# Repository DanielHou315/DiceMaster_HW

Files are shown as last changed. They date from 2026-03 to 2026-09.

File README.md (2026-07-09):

# DiceMaster HW

Hardware design files for the DiceMaster project, using KiCad.

## Board Status

The current production board is **PCB v1** (`PCB/DiceMaster_Router/`), finalized
for production on 2026-04-05 (commit `4ef69b5`, "finalized pcb v1 for prod").
Gerbers and the JLCPCB BOM under `PCB/DiceMaster_Router/gerbers/` are from this
run; the manufactured boards were received around mid-April 2026.

### Known issues (PCB v1 — unverified, to be handled later)

These issues were observed on the v1 boards but **not yet root-caused**:

1. **Some JST ports could not be soldered during manufacturing.** One or more of
   the JST GH SMD connectors (`J_A1`–`J_F1`, `J_BTN1`, `J_SWITCH1`, `J_FAN1`,
   `PiSugarPowerConnector1` — see `docs/runbooks/pcb-assembly.md` §4) could not
   be soldered on during assembly. Cause not yet determined (footprint/pad
   geometry vs. process).

2. **5V→3.3V converter does not work.** The onboard buck converter (IC1,
   TPS565201, SOT-23-6) did not produce a working 3.3 V rail after hand-soldering
   the part. It is **not yet known whether this is a design issue or a soldering
   issue** — this needs to be re-verified before the next production run. See the
   "No 3.3 V output" row in `docs/runbooks/pcb-assembly.md` §Troubleshooting and
   the converter subcircuit (IC1 / L1 / R_BOT1 / output caps) in the schematic.

> Status: both issues are **open and unverified**. Do not assume v1 boards have a
> working 3.3 V rail. Revisit during the next hardware bring-up / v2 design.

## KiCad MCP Server Setup

This project is configured with [kicad-mcp](https://github.com/lamaalrajih/kicad-mcp) to enable Claude Code to interact with KiCad projects directly.

### Prerequisites

- KiCad 9.0+ (installed at `/Applications/KiCad/KiCad.app`)
- Python 3.10+ and `uv`

### Installation

The MCP server is installed at `~/Applications/kicad-mcp`. To reinstall:

```bash
git clone https://github.com/lamaalrajih/kicad-mcp.git ~/Applications/kicad-mcp
cd ~/Applications/kicad-mcp
make install
cp .env.example .env
# Edit .env to set KICAD_SEARCH_PATHS to your project directory
```

### Usage

Start Claude Code from this directory — the `.mcp.json` file automatically connects the KiCad MCP server.

```bash
cd DiceMaster_HW
claude
```

Claude can then:

- **List projects** — discover KiCad projects in the configured search paths
- **Open projects** — launch KiCad with a specific project
- **Inspect schematics** — read components, nets, and symbols
- **Analyze PCBs** — view board properties, footprints, and design rules
- **Manage libraries** — search and retrieve KiCad symbols/footprints

### Configuration

- **`.mcp.json`** — MCP server config (points to the kicad-mcp installation)
- **`~/Applications/kicad-mcp/.env`** — KiCad paths and project search directories

To add more search paths, edit `~/Applications/kicad-mcp/.env`:

```
KICAD_SEARCH_PATHS=~/Code/DiceMaster/DiceMaster_HW,~/other/projects
```

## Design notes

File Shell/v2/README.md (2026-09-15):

# DiceMaster Shell v2

## BOM

**3D Prints**

- 1x Base Frame
- 1x Base Inserts/USB SW Plate
- 1x Base Inserts/Button Plate (for future use)
- 1x Screen Backplate With Fan
- 5x Screen Backplate

Print in PLA at 20% infill. 

**Components**

- 1x [Raspberry Pi CM4 with 16GB+ eMMC storage](https://www.newark.com/raspberry-pi/cm4102016/rpi-module-4-2gb-ram-16gb-emmc/dp/86AH2097)
- 1x [WaveShare CM4 Nano Base Board (B)](https://www.waveshare.com/cm4-nano-b.htm)
- 6x [AdaFruit 4' 480x480 NoTouch Screen](https://www.adafruit.com/product/5827)
- 6x [AdaFruit Qualia ESP32-S3 for TTL RGB-666 Displays](https://www.adafruit.com/product/5800)
- 1x custom PCB board
- 1x [30mm blower fan](https://www.amazon.com/WINSINN-Blower-Hydraulic-Bearing-Turbine/dp/B08MKRL4GS)
- 1x 10cm USB-C to USB-C cable
- 1x 15cm USB-C to USB-C cable
- 1x [USB-A to USB-C adapter](https://www.amazon.com/Female-Male-Adapter-3Pack-Gray/dp/B07Z66MK6L)
- Abundant JST-GH connectors
- Abundant M2.5 x 6mm screws
- Abundant M2.5 * 8mm screws
- Abundant Wires
- Abundant 1/8 inch clear Acrylic

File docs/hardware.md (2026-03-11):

# Programmable Dice Hardware

We used
- [Adafruit LCD 4’ square display ](https://www.adafruit.com/product/5827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)
- [Esp32-s3 controller](https://www.adafruit.com/product/5800) for the above display. [Guides for using the board](https://learn.adafruit.com/adafruit-qualia-esp32-s3-for-rgb666-displays). 
- We name a Screen Module an assembly of the above screen and an ESP 32 processor along with its external shell. 

## Dimensions (for physical design)

ESP32 Board
- Board dimensions: 44.35 x 51.7mm. 
- Between holes: 31.15 x 36.85
- Hole dimension: 2.5mm (~0.1 inch).

Screen: 
- Board dimensions: 75.00mm x 79.10mm

Raspberry Pi 3B+ board: 
- Between holes: 49 x 58 mm
- Hole dimension: 2.5mm

PiSugar 3S Battery
- Holes same as above, height 19mm

Raspberry Pi Compute Module 4 
- Board dimensions: 40 x 55mm
- Between holes 33 x 48 mm
- Hole dimension: 2.5 mm

## Pinout Design

- [Raspberry Pi pinout](https://pinout.xyz/)
- [ESP-32 S3 guide](https://learn.adafruit.com/adafruit-qualia-esp32-s3-for-rgb666-displays)
- [Connecting screen to Raspberry Pi](https://pinout.xyz/pinout/spi)
- [Connecting MPU6050](https://www.instructables.com/How-to-Use-the-MPU6050-With-the-Raspberry-Pi-4/)

## Electrical Design

### Data Lines
**Screens**
We use 3 SPI buses to connect a total of six screens. To minimize CS switching time, we design an application layer protocol that is similar to CAN, where devices choose to accept/respond to messages based on the device ID. 

SPI 0: 
- SCK: 23
- MISO: 21 (not used)
- MOSI: 19
- CS: 24 (for both screens)

SPI 1: 
- SCK: 40
- MISO: 35 (not used)
- MOSI: 38
- CS: 12 (for both screens)

SPI 3: 
- SCK: 5
- MISO: 28 (not used)
- MOSI: 3
- CS: 27 (for both screens)

**IMU/Battery**
IMU and Battery uses I2C6. 
- SDA: 15
- SCL: 16

**Power Switch**

**Status LED**

**Buttons**

### Power Lines

### PCB

Yuzhen is working on this

## HW v2

### Reliability

### Cost Reduction

**Whiteboard version**: 

[Example dice](https://www.amazon.com/Scribbledo-Multipurpose-Colorful-Educational-Classroom/dp/B0B3S75YCV). 

### Batter Life Improvement

For HW v1, the batter lasts about 45 minutes when all displays are active, as was tested during serious play.

### Additional features

1. Cooling: adding a fan for Raspberry Pi, air channels, and optimized layout of 5V to 3.3V regulators. 
2.

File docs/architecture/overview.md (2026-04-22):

# Hardware Architecture Overview

## Summary

DiceMaster is a programmable electronic die with six faces. Each face displays a screen driven by a dedicated ESP32-S3 processor. A central Raspberry Pi (CM4 or 3B+) coordinates all six faces over SPI and reads orientation from an IMU over I2C. A TPS565201 buck converter on the Router PCB steps the battery voltage down to 3.3 V for all logic.

---

## Boards and Modules

### Raspberry Pi (Central Controller)

The Raspberry Pi acts as the main application processor. Either a Raspberry Pi 3B+ or a Compute Module 4 (CM4) is supported:

- **Raspberry Pi 3B+**: 85 × 56 mm, mounting holes 49 × 58 mm apart, 2.5 mm diameter.
- **Raspberry Pi CM4**: 40 × 55 mm, mounting holes 33 × 48 mm apart, 2.5 mm diameter.

The Pi runs the `dicemaster_central` ROS 2 package and owns the SPI and I2C buses.

### DiceMaster Router PCB (`PCB/DiceMaster_Router/`)

The Router is a custom 2-layer KiCad PCB (≤ 60 × 60 mm, 1 oz copper) that acts as the electrical hub of the dice. It provides:

- A **2×20 pin female header (J1)** that mates directly to the Raspberry Pi 40-pin GPIO header.
- **Six JST GH 6-pin connectors (J_A1–J_F1)**, one per screen/ESP32 face module, carrying SPI data lines and 3.3 V power.
- A **TPS565201DDCR** synchronous buck regulator (5 V → 3.3 V, SOT-23-6) with supporting passives (L1, C1/C3/C_OUT1-3, R_Top1/R_BOT1, C_BST1).
- A **2N7002 N-channel MOSFET (Q_FAN1)** and **1N5819 Schottky diode (D_FAN1)** for PWM-controlled fan driving.
- A **GY-BMI160 IMU breakout** socket (U1, 7+5 pin headers, 10.16 mm row spacing) for orientation sensing over I2C.
- A **JST GH 5-pin connector (J_BTN1)** for the button array.
- A **JST GH 3-pin connector (J_SWITCH1)** for the power switch.
- A **JST GH 2-pin connector (J_FAN1)** for the 30 mm 5 V blower fan.
- A **JST GH 2-pin connector (PiSugarPowerConnector1)** for the PiSugar 3S battery board.

Custom KiCad symbols and footprints for the TPS565201 and BMI160 breakout live in `PCB/DiceMaster_Router/Components/` and `Components.pretty/`.

### Screen Modules (× 6)

Each screen module is an assembly of:

- **Adafruit 4-inch square RGB666 LCD** (Adafruit #5827), PCB 75.00 × 79.10 mm.
- **Adafruit Qualia ESP32-S3 controller** (Adafruit #5800), PCB 44.35 × 51.7 mm, mounting holes 31.15 × 36.85 mm apart, 2.5 mm diameter.
- A physical shell that forms one face of the die enclosure (see Enclosure below).

Each ESP32-S3 receives commands from the Pi over SPI and drives its attached display directly.

### PiSugar 3S Battery Board

The PiSugar 3S attaches to the underside of the Raspberry Pi. Its mounting holes match the Pi's 49 × 58 mm pattern. It connects to the Router PCB via `PiSugarPowerConnector1`. Battery life is approximately 45 minutes with all six displays active.

---

## Interconnects

### SPI (Pi → ESP32-S3 face modules)

Three SPI buses each carry two face modules. All six modules share a CAN-inspired application-layer protocol: each ESP32-S3 accepts or ignores messages based on a device ID, so a single CS line per bus services two modules without per-device chip-select toggling.

| Bus | SCK | MOSI | MISO (unused) | CS |
|---|-----|---|---|----|
| SPI 0 | 23  | 19 | 21 | 24 |
| SPI 1 | 40  | 38 | 35 | 12 |
| SPI 3 | 5 | 3 | 28 | 27 |

Pin numbers are Raspberry Pi physical/BCM GPIO as documented at [pinout.xyz](https://pinout.xyz/pinout/spi).

Each face module connects to the Router PCB via a JST GH 6-pin cable (J_A1–J_F1), carrying SCK, MOSI, CS, 3.3 V, and GND.

### I2C (Pi → IMU and Battery)

The BMI160 IMU breakout and PiSugar battery management share **I2C bus 6**:

- SDA: GPIO 15
- SCL: GPIO 16

### Power Distribution

```
Battery (LiPo via PiSugar 3S)
  └─► PiSugar board → Raspberry Pi (5 V USB-style)
  └─► Router PCB PiSugarPowerConnector1
        └─► TPS565201 buck converter (5 V → 3.3 V)
              └─► 3.3 V rail → six face module JST connectors
              └─► 3.3 V rail → logic on Router PCB
  └─► Fan connector (5 V, MOSFET-switched via Q_FAN1)
```

---

## Enclosure (shell/)

The `shell/` directory holds the physical enclosure design files for the dice body. The shell is shaped as a cube with six flat faces; each face seats one screen module assembly. The enclosure design is currently a placeholder — no CAD files have been added yet.

Reference for physical form factor: [Scribbledo foam cube dice](https://www.amazon.com/Scribbledo-Multipurpose-Colorful-Educational-Classroom/dp/B0B3S75YCV).

---

## HW v1 vs v2

**v1** used Adafruit dev boards with external wiring. Battery life was ~45 minutes under full load.

**v2 goals** (in progress): custom compact PCB (this Router board), improved battery life, cooling fan, optimized 5 V→3.3 V regulator layout, and reduced cost via bare modules.

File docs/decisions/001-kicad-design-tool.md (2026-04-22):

# ADR-001: KiCad as PCB Design Tool

## Status

Accepted

## Context

DiceMaster requires custom PCB design for the Router board. The design files must be:

- Stored in Git alongside the rest of the project source.
- Reproducible on any developer machine without a paid license or cloud dependency.
- Compatible with standard PCB fabrication services (JLCPCB, PCBWay) that accept Gerber outputs.

The team is a small hardware/software group on macOS and Linux. Tooling cost and vendor lock-in are primary concerns.

## Decision

Use **KiCad 9.0+** as the sole PCB design tool.

- The project file is `PCB/DiceMaster_Router/DiceMaster_Router.kicad_pro`.
- Schematics use `.kicad_sch` format; board layout uses `.kicad_pcb`.
- Custom symbols and footprints specific to this project (TPS565201, BMI160 breakout) live in `PCB/DiceMaster_Router/Components/` and `Components.pretty/` and are checked into Git.
- Gerber outputs are committed to `PCB/DiceMaster_Router/gerbers/` for traceability.
- The project is configured with a [kicad-mcp](https://github.com/lamaalrajih/kicad-mcp) server so Claude Code can inspect schematics and PCB files directly.

## Consequences

**Positive:**

- KiCad is free and open-source (GPL). No license cost.
- All file formats (`.kicad_sch`, `.kicad_pcb`, `.kicad_pro`) are plain text (S-expression). Git diffs are human-readable and merge conflicts are resolvable.
- Ships with a large built-in symbol and footprint library covering most standard passive and active components.
- Cross-platform: runs on macOS, Linux, and Windows.
- Gerber export is well-supported and accepted by all major PCB fabs.

**Negative:**

- Steeper initial learning curve than Eagle's legacy UI or EasyEDA's guided workflow.
- KiCad's scripting API (Python) is powerful but sparsely documented compared to commercial tools.
- Version upgrades (e.g., KiCad 8 → 9) occasionally change file formats, requiring migration.

## Alternatives Considered

**Eagle (Autodesk)**
Eagle was the de-facto hobbyist standard before Autodesk acquisition. It is now bundled with Fusion 360 under a subscription model. File format is proprietary XML; while text-based, diffs are noisy and imports into other tools are lossy. Rejected due to cost and vendor lock-in.

**EasyEDA (LCSC/JLCPCB)**
Browser-based tool tightly integrated with JLCPCB's component catalog. Convenient for ordering, but files live in the cloud, offline access is limited, and version control requires manual JSON export. Rejected because reproducibility and Git integration are first-class requirements for this project.

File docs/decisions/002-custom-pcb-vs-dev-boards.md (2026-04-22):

# ADR-002: Custom PCB vs Off-the-Shelf Dev Boards

## Status

Accepted

## Context

DiceMaster needs to fit a Raspberry Pi, six ESP32-S3 screen controllers, an IMU, a battery board, a buck regulator, and a cooling fan inside a cube-shaped enclosure. The enclosure face dimensions are constrained by the 75 × 79 mm screen panels.

**Prototype v1** used off-the-shelf Adafruit dev boards (Adafruit Qualia ESP32-S3 #5800, 44.35 × 51.7 mm each) wired together with jumper cables. This proved the software stack but exposed hardware problems:

- The Qualia ESP32-S3 dev boards protrude connectors (USB-C, JST, headers) on all four edges, making flush face mounting impossible.
- Six individual dev boards plus a breadboard-style wiring harness do not fit reliably inside the enclosure.
- Loose jumper wire connections caused intermittent SPI failures during handling.
- Battery life was ~45 minutes under full load, partly due to inefficient power distribution.

A production-grade design requires tight, mechanically stable integration.

## Decision

Use a **custom DiceMaster Router PCB** (in `PCB/DiceMaster_Router/`) that centralises all inter-board routing.

Key design choices on the custom PCB:

- **Bare ESP32-S3 modules** (via Adafruit Qualia boards retained for now, connected via JST GH 6-pin cables rather than loose jumpers) replace the prototype wiring harness.
- **JST GH 6-pin connectors (J_A1–J_F1)** provide one keyed, latching connector per face — no loose wires.
- **TPS565201 buck converter** on the Router board provides a regulated 3.3 V rail directly, eliminating per-board linear regulators.
- The Router board footprint is ≤ 60 × 60 mm so it fits beneath the Pi inside the enclosure.
- Gerbers are committed and have been ordered from JLCPCB with SMD assembly for passive components.

## Consequences

**Positive:**

- Compact, mechanically reliable form factor — all inter-board connections are short, keyed cables.
- Centralised power regulation reduces heat and improves efficiency over per-board LDOs.
- Production-ready: the PCB can be re-ordered from JLCPCB using the committed Gerber and BOM files.
- Eliminates the intermittent SPI failures seen with jumper wiring.

**Negative:**

- PCB manufacturing lead time (~5–7 business days for JLCPCB standard service) slows hardware iteration.
- SMD soldering or PCBA service required for passive components; hand-soldering the TPS565201 SOT-23-6 demands fine-pitch skill.
- A PCB spin is needed to change any electrical interface.

## Alternatives Considered

**Prototype v1: dev boards with breakout wiring**
Used in the initial prototype. Fast to iterate, but mechanically unreliable and physically too large for the target enclosure. Retained as a software development reference only.

**Flexible PCB (FPC)**
An FPC could route connections along the inside faces of the cube enclosure. Rejected for v2 because FPC tooling and design complexity is significantly higher, and the rigid Router PCB approach already solves the mechanical reliability problem at lower cost.

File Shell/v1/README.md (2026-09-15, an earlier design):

# DiceMaster Shell v1

The v1 shell (concluded Aug 8, 2025), is a fast prototype design with exoskeleton-like design. It is designed to be easier for fast iteration and

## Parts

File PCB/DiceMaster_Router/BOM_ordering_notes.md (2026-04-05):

# DiceMaster Router - BOM & Ordering Notes

## JLCPCB SMD Assembly Parts

### Resistors (0402, 1%)
| Ref | Value | Package | Notes |
|-----|---|---|---|
| R_FG1 | 1kΩ | 0402 | MOSFET gate resistor |
| R_FPD1 | 100kΩ | 0402 | MOSFET gate pull-down |
| R_Top1 | 100kΩ | 0402 | TPS565201 feedback divider top |
| R_BOT1 | 30.1kΩ | 0402 | TPS565201 feedback divider bottom. **Must be 1% tolerance** — sets 3.3V output voltage |

### Capacitors (0402 / 0805)
| Ref | Value | Package | Notes |
|-----|---|---|---|
| C_BST1 | 100nF | 0402 | TPS565201 bootstrap cap |
| C1 | 22µF | 0805 | TPS565201 input cap. **Must be ≥10V rated.** e.g., Samsung CL21A226MAQNNNE |
| C3 | 22µF | 0805 | TPS565201 input cap. Same spec as C1 |
| C_OUT1 | 22µF | 0805 | TPS565201 output cap. ≥10V rated |
| C_OUT2 | 22µF | 0805 | TPS565201 output cap. ≥10V rated |
| C_OUT3 | 22µF | 0805 | TPS565201 output cap. ≥10V rated |

**WARNING:** 0805 22µF ceramic caps at 6.3V rating have severe DC bias derating — at 5V they may only provide ~10µF effective capacitance. Always pick **≥10V rated** parts to maintain full capacitance at operating voltage.

### Inductor
| Ref | Value | Package | Notes |
|-----|---|---|---|
| L1 | 3.3µH | 5x5mm (NR-50xx) | Power inductor for TPS565201. **Must be rated ≥3A saturation current.** Search JLCPCB for "3.3uH 5040" or "3.3uH 5020". e.g., Sunlord SWPA5040S3R3NT |

### Semiconductor
| Ref | Value | Package | Notes |
|-----|---|---|---|
| IC1 | TPS565201DDCR | SOT-23-6 (SOT95P280X110-6N) | 5V→3.3V buck converter |
| Q_FAN1 | 2N7002 | SOT-23 | N-channel MOSFET, fan driver. 115mA max continuous |
| D_FAN1 | 1N5819 | SOD-323 | Schottky flyback diode. SOD-323 equivalent: 1N5819HW or B5819W |

### Fan Current Budget
- Fan: WINSINN 30mm 5V Blower (0.09A / 0.5W)
- Q_FAN (2N7002) rated 115mA continuous
- Margin: 26mA (23%) — acceptable for this fan, but do NOT substitute a larger fan without upgrading the MOSFET (e.g., IRLML6344 for >1A fans)

## Hand-Soldered Connectors

| Ref | Part | Notes |
|-----|---|---|
| J1 | 2x20 pin socket header, 2.54mm | Raspberry Pi 40-pin female header |
| J_A1–J_F1 | SM06B-GHS-TB | JST GH 6-pin SMD horizontal |
| J_BTN1 | SM05B-GHS-TB | JST GH 5-pin SMD horizontal |
| J_SWITCH1 | SM03B-GHS-TB | JST GH 3-pin SMD horizontal |
| J_FAN1 | SM02B-GHS-TB | JST GH 2-pin SMD horizontal |
| PiSugarPowerConnector1 | SM02B-GHS-TB | JST GH 2-pin SMD horizontal |

## IMU Breakout (separate board, plugs in)

| Part | Notes |
|---|---|
| GY-BMI160 | 18.3mm × 13.3mm breakout board. Mounts via pin headers into U1 footprint (7+5 pin, 10.16mm row spacing, 2.54mm pitch) |

## PCB Specs for JLCPCB Order
- Max board size: 60mm × 60mm
- Layers: 2 (or 4 if routing is tight)
- Copper weight: 1oz standard
- Surface finish: HASL or LeadFree HASL

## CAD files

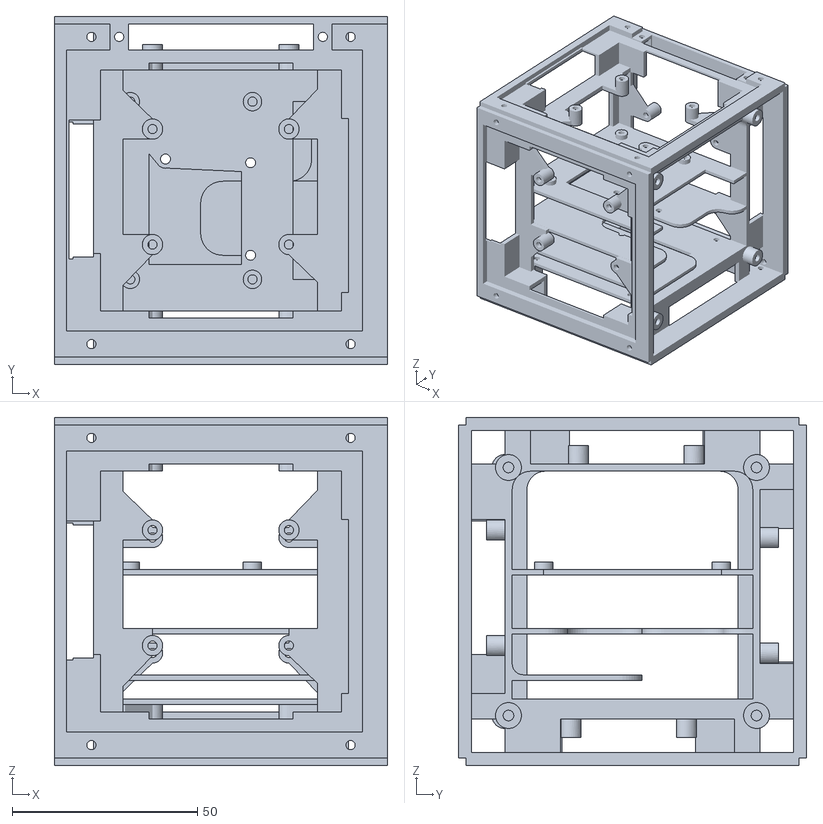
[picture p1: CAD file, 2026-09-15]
Shell/v2/Base Frame/Base Frame.stl
90.0 x 94.0 x 94.0

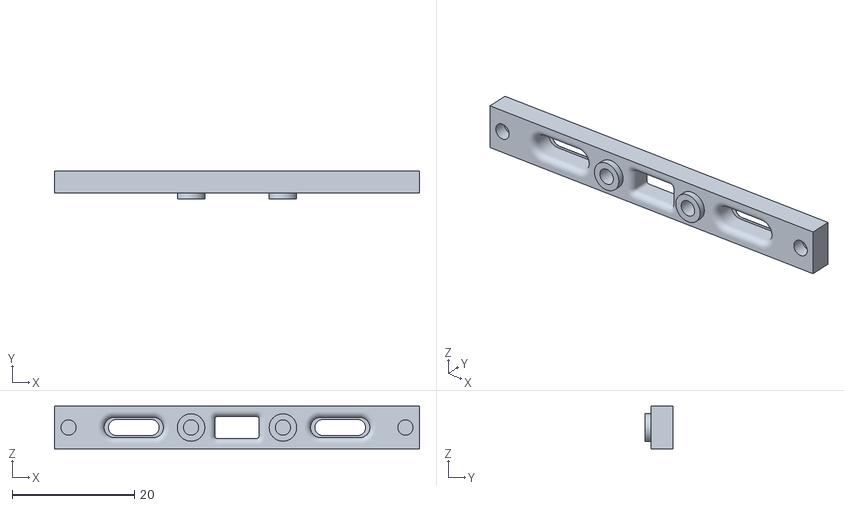
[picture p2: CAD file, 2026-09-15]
Shell/v2/Base Inserts/USB SW Plate.stl
59.6 x 4.53 x 7.00

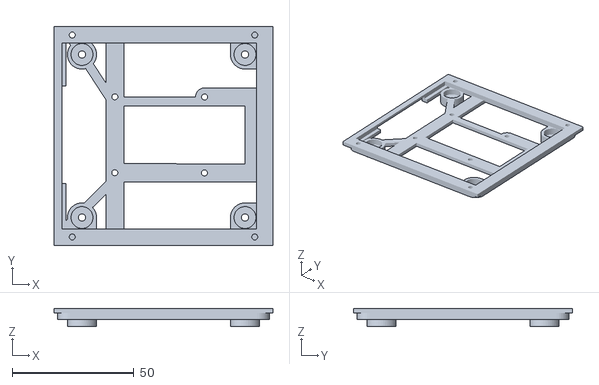
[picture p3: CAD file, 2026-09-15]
Shell/v2/Screen Backplate/Screen BackPlate.stl
90.0 x 90.0 x 7.50

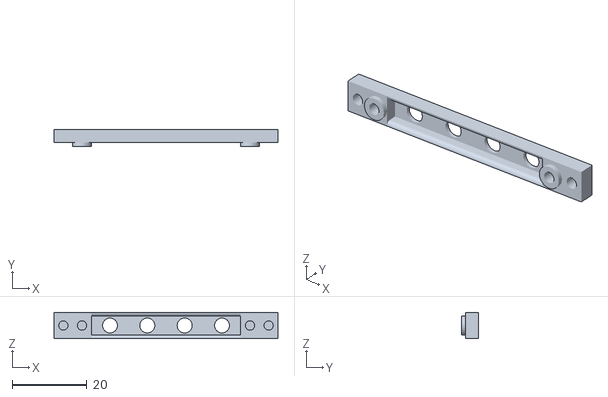
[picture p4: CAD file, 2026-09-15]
Shell/v2/Base Inserts/Button Plate.stl
60.0 x 4.53 x 7.00

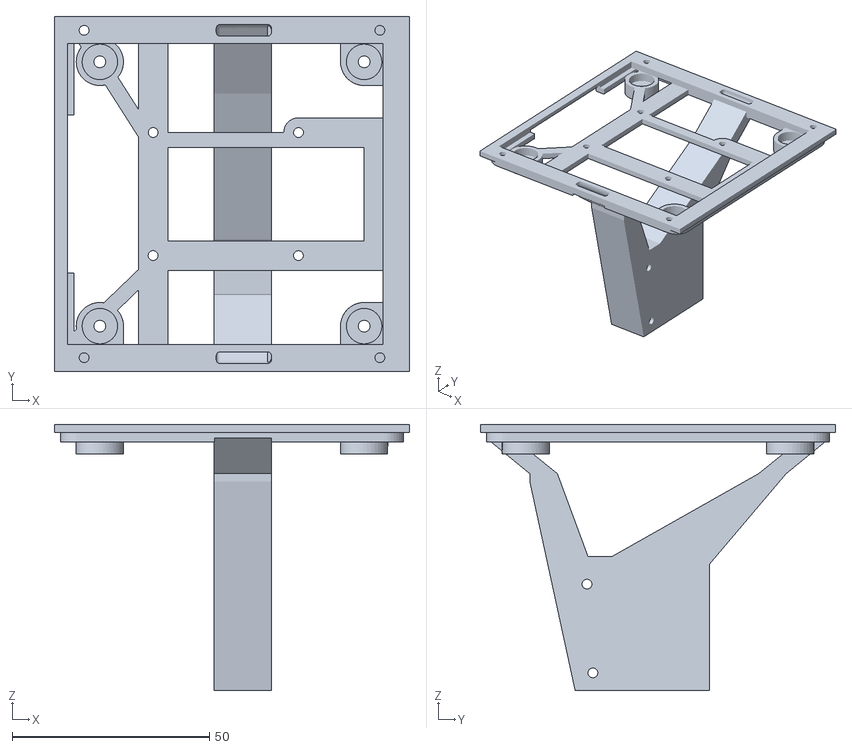
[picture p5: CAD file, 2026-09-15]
Shell/v2/Screen Backplate/Screen Backplate With Fan.stl
90.0 x 90.0 x 67.5

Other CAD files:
Shell/v2/Base Frame/Base Frame.f3d
Shell/v2/Base Inserts/Button Plate.f3d
Shell/v2/Base Inserts/USB SW Plate.f3d
Shell/v2/Screen Backplate/Screen Backplate With Fan.f3d
Shell/v2/Screen Backplate/Screen Backplate.f3d

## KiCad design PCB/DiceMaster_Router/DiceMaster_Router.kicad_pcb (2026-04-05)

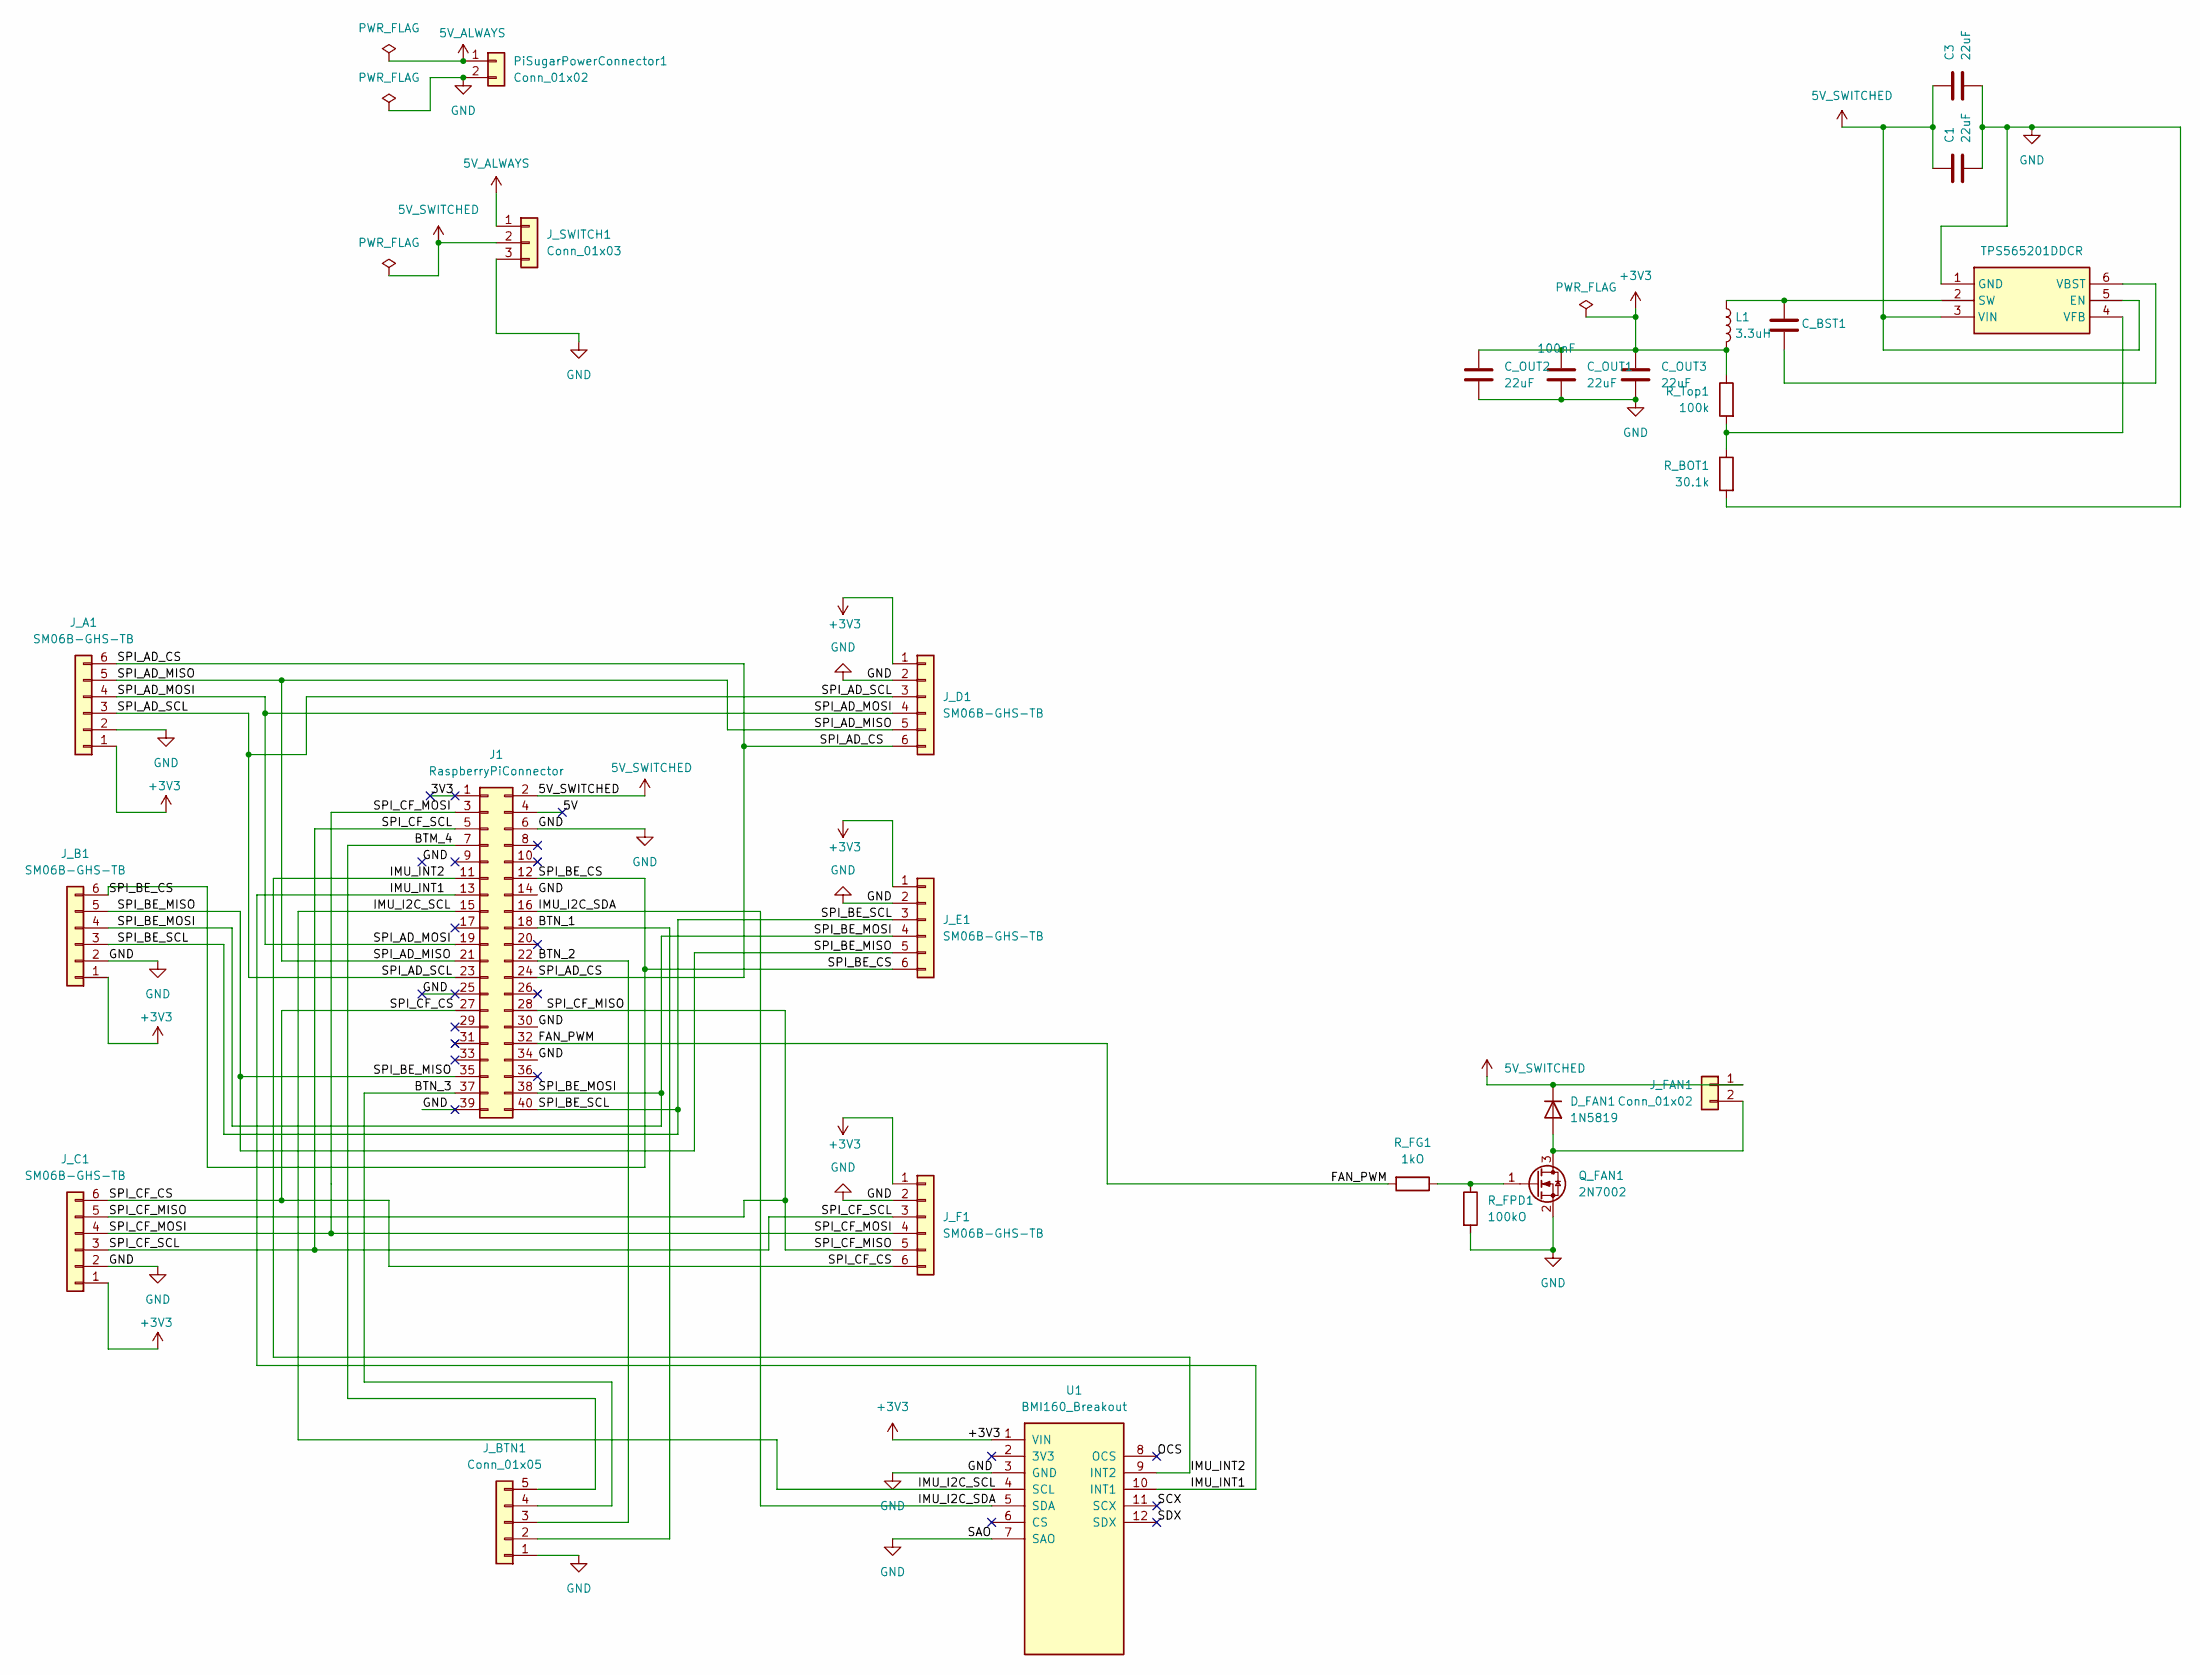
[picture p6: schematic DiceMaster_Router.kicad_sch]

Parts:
C1, C3: 22uF; C_0805_2012Metric
C_BST1: 100nF; C_0402_1005Metric
C_OUT1, C_OUT2, C_OUT3: 22uF; C_0805_2012Metric
D_FAN1: 1N5819; D_SOD-323
IC1: TPS565201DDCR; SOT95P280X110-6N; Manufacturer_Part_Number TPS565201DDCR; Mouser Part Number 595-TPS565201DDCR
J1: RaspberryPiConnector; PinSocket_2x20_P2.54mm_Vertical
J_A1: SM06B-GHS-TB; JST_GH_SM06B-GHS-TB_1x06-1MP_P1.25mm_Horizontal
J_B1: SM06B-GHS-TB; JST_GH_SM06B-GHS-TB_1x06-1MP_P1.25mm_Horizontal
J_BTN1: Conn_01x05; JST_GH_SM05B-GHS-TB_1x05-1MP_P1.25mm_Horizontal
J_C1: SM06B-GHS-TB; JST_GH_SM06B-GHS-TB_1x06-1MP_P1.25mm_Horizontal
J_D1: SM06B-GHS-TB; JST_GH_SM06B-GHS-TB_1x06-1MP_P1.25mm_Horizontal
J_E1: SM06B-GHS-TB; JST_GH_SM06B-GHS-TB_1x06-1MP_P1.25mm_Horizontal
J_F1: SM06B-GHS-TB; JST_GH_SM06B-GHS-TB_1x06-1MP_P1.25mm_Horizontal
J_FAN1: Conn_01x02; JST_GH_SM02B-GHS-TB_1x02-1MP_P1.25mm_Horizontal
J_SWITCH1: Conn_01x03; JST_GH_SM03B-GHS-TB_1x03-1MP_P1.25mm_Horizontal
L1: 3.3uH; L_Taiyo-Yuden_NR-50xx
PiSugarPowerConnector1: Conn_01x02; JST_GH_SM02B-GHS-TB_1x02-1MP_P1.25mm_Horizontal
Q_FAN1: 2N7002; SOT-23
R_BOT1: 30.1k; R_0402_1005Metric
R_FG1: 1kO; R_0402_1005Metric
R_FPD1: 100kO; R_0402_1005Metric
R_Top1: 100k; R_0402_1005Metric
U1: BMI160_Breakout

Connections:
5V_ALWAYS: J_SWITCH1.1, PiSugarPowerConnector1.1
5V_SWITCHED: C1.1, C3.1, D_FAN1.1 (K), IC1.3 (VIN), IC1.5 (EN), J1.2, J_FAN1.1, J_SWITCH1.2
+3V3: C_OUT1.1, C_OUT2.1, C_OUT3.1, J_A1.1, J_B1.1, J_C1.1, J_D1.1, J_E1.1, J_F1.1, L1.2, R_Top1.1, U1.1 (VIN)
/3V3: J1.1
/5V: J1.4
/BTM_4: J1.7, J_BTN1.5
/BTN_1: J1.18, J_BTN1.2
/BTN_2: J1.22, J_BTN1.3
/BTN_3: J1.37, J_BTN1.4
/FAN_PWM: J1.32, R_FG1.2
/IMU_I2C_SCL: J1.15, U1.4 (SCL)
/IMU_I2C_SDA: J1.16, U1.5 (SDA)
/IMU_INT1: J1.13, U1.10 (INT1)
/IMU_INT2: J1.11, U1.9 (INT2)
/OCS: U1.8 (OCS)
/SCX: U1.11 (SCX)
/SDX: U1.12 (SDX)
/SPI_AD_CS: J1.24, J_A1.6, J_D1.6
/SPI_AD_MISO: J1.21, J_A1.5, J_D1.5
/SPI_AD_MOSI: J1.19, J_A1.4, J_D1.4
/SPI_AD_SCL: J1.23, J_A1.3, J_D1.3
/SPI_BE_CS: J1.12, J_B1.6, J_E1.6
/SPI_BE_MISO: J1.35, J_B1.5, J_E1.5
/SPI_BE_MOSI: J1.38, J_B1.4, J_E1.4
/SPI_BE_SCL: J1.40, J_B1.3, J_E1.3
/SPI_CF_CS: J1.27, J_C1.6, J_F1.6
/SPI_CF_MISO: J1.28, J_C1.5, J_F1.5
/SPI_CF_MOSI: J1.3, J_C1.4, J_F1.4
/SPI_CF_SCL: J1.5, J_C1.3, J_F1.3
GND: C1.2, C3.2, C_OUT1.2, C_OUT2.2, C_OUT3.2, IC1.1 (GND), J1.6, J1.14, J1.25, J1.30, J1.34, J1.39, J_A1.2, J_B1.2, J_BTN1.1, J_C1.2, J_D1.2, J_E1.2, J_F1.2, J_SWITCH1.3, PiSugarPowerConnector1.2, Q_FAN1.2 (S), R_BOT1.2, R_FPD1.2, U1.3 (GND), U1.7 (SAO)
unnamed: D_FAN1.2 (A), J_FAN1.2, Q_FAN1.3 (D)
unnamed: C_BST1.1, IC1.2 (SW), L1.1
unnamed: C_BST1.2, IC1.6 (VBST)
unnamed: IC1.4 (VFB), R_BOT1.1, R_Top1.2
unnamed: Q_FAN1.1 (G), R_FG1.1, R_FPD1.1

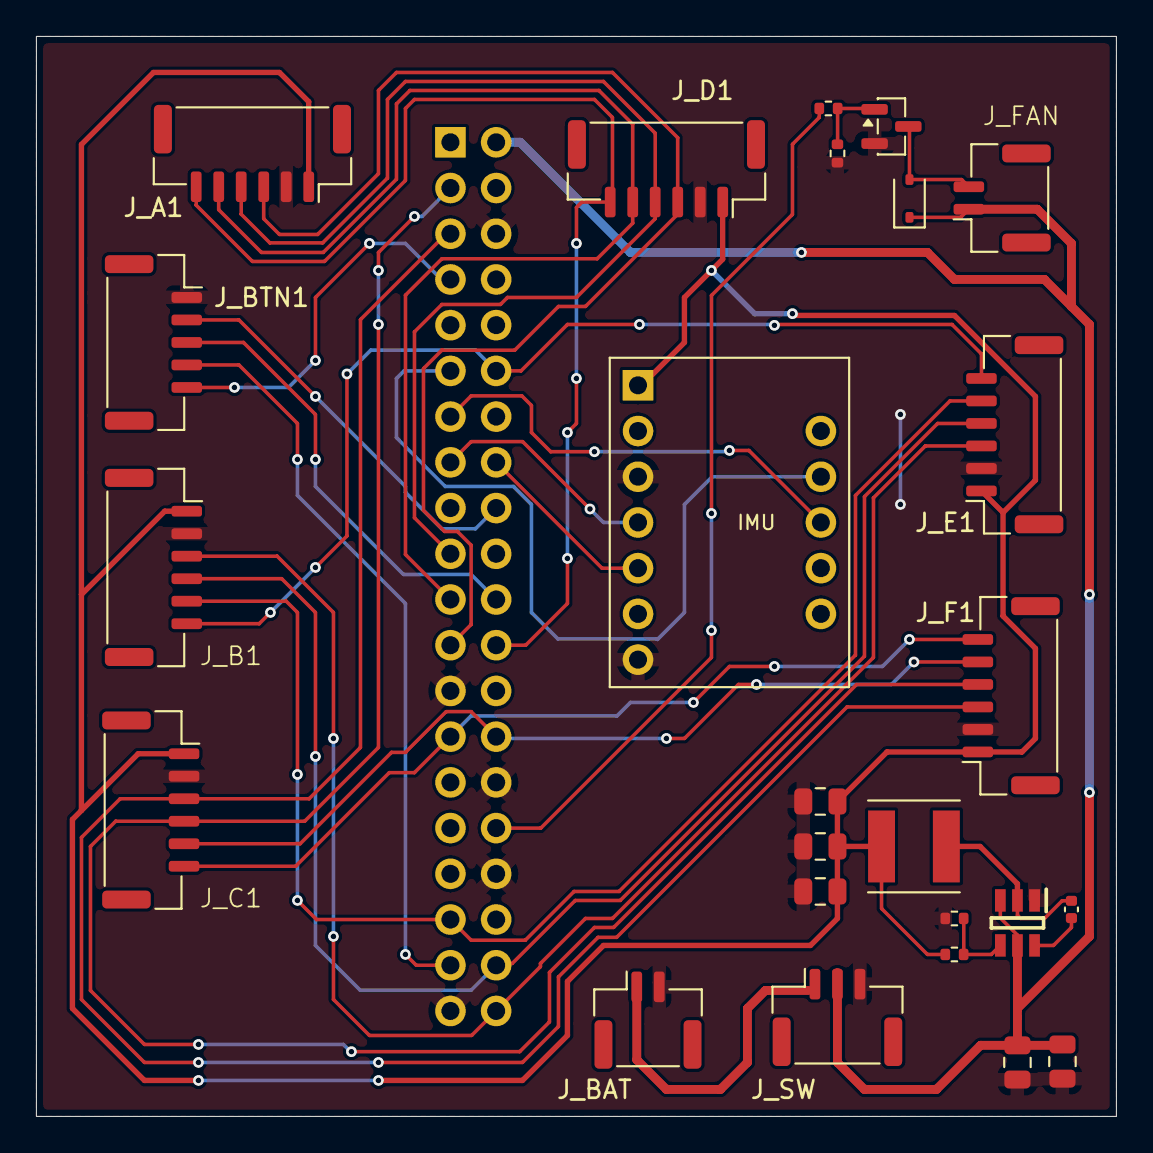
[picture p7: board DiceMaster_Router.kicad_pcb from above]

Board: 2 copper layers, 60.0 x 60.0 mm, 26 parts (1 on the bottom side), 30 nets.

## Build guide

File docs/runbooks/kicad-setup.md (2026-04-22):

# Runbook: KiCad Project Setup

## Prerequisites

- macOS (or Linux/Windows) with administrator access.
- KiCad 9.0 or later. Download from [kicad.org](https://www.kicad.org/download/).
  - macOS default install path: `/Applications/KiCad/KiCad.app`.
- Python 3.10+ and `uv` (for the kicad-mcp server, if using Claude Code integration).
- The `DiceMaster_HW` repository cloned locally (this repo contains the `.kicad_pro` file).

## Steps

### 1. Install KiCad

Download and install KiCad 9.0+ from [kicad.org](https://www.kicad.org/download/). Accept the default install location. KiCad bundles its own footprint and symbol libraries — no separate library install is needed for standard parts.

### 2. Open the Project

1. Launch **KiCad**.
2. Select **File → Open Project**.
3. Navigate to `DiceMaster_HW/PCB/DiceMaster_Router/` and open `DiceMaster_Router.kicad_pro`.
4. The KiCad project manager opens, showing links to the schematic (`DiceMaster_Router.kicad_sch`) and PCB layout (`DiceMaster_Router.kicad_pcb`).

### 3. Install Project-Local Footprint Libraries

The Router project uses custom footprints for the TPS565201 (SOT-23-6 variant) stored in `PCB/DiceMaster_Router/Components.pretty/`. These are referenced via a project-local `fp-lib-table` file already committed to the repo — KiCad loads them automatically when the project is opened from its directory.

To verify:
1. Open the **PCB Editor** (click the PCB layout icon in the project manager).
2. Go to **Preferences → Manage Footprint Libraries**.
3. The **Project Specific Libraries** tab should list `Components` pointing to `${KIPRJMOD}/Components.pretty`.

If the library is missing or shows a path error, click **Add Existing** and browse to `PCB/DiceMaster_Router/Components.pretty/`.

Similarly, custom schematic symbols are in `PCB/DiceMaster_Router/Components/` and referenced in `sym-lib-table`. Verify under **Schematic Editor → Preferences → Manage Symbol Libraries**.

### 4. Configure the kicad-mcp Server (Claude Code Integration)

The `.mcp.json` file in `DiceMaster_HW/` configures the kicad-mcp server for Claude Code. This lets Claude inspect schematics and PCB files interactively.

**Install the server:**

```bash
git clone https://github.com/lamaalrajih/kicad-mcp.git ~/Applications/kicad-mcp
cd ~/Applications/kicad-mcp
make install
cp .env.example .env
```

**Edit `~/Applications/kicad-mcp/.env`** to set the search path:

```
KICAD_SEARCH_PATHS=~/Code/DiceMaster/DiceMaster_HW
```

**Start Claude Code from the project directory** so `.mcp.json` is picked up automatically:

```bash
cd DiceMaster_HW
claude
```

Claude can then list projects, open KiCad, inspect schematics, analyze PCB layout, and search the footprint library.

### 5. Run DRC Before Exporting

Always run the Design Rules Checker before exporting Gerbers or sharing the board file:

1. Open the **PCB Editor**.
2. Go to **Inspect → Design Rules Checker**.
3. Click **Run DRC**.
4. Resolve all **Errors** (warnings may be acceptable, but document any intentional rule exceptions).

Common DRC items to watch for in this design:
- Clearance violations near the TPS565201 SOT-23-6 pads (dense layout).
- Courtyard overlaps if components are placed tightly.
- Unconnected nets (indicates a ratsnest was missed during routing).

### 6. Export Gerbers

After DRC passes, see the [PCB Assembly runbook](pcb-assembly.md) for the full Gerber export and ordering workflow.

## Verify

- KiCad project opens without missing library warnings.
- Schematic loads all symbols without "symbol not found" errors.
- PCB layout shows all footprints placed and all ratsnest connections routed.
- DRC reports zero errors.

## Troubleshooting

| Symptom | Likely Cause | Fix |
|---|---|-----|
| "Symbol not found" in schematic | `sym-lib-table` path broken after repo move | Re-add `Components/` under **Manage Symbol Libraries → Project Specific** |
| "Footprint not found" in PCB editor | `fp-lib-table` path broken | Re-add `Components.pretty/` under **Manage Footprint Libraries → Project Specific** |
| kicad-mcp server not connecting | `.env` path wrong, or `uv` not installed | Verify `KICAD_SEARCH_PATHS` in `.env`; run `which uv` to confirm `uv` is on PATH |
| DRC reports clearance errors | Component placement too tight | Use the interactive router's push-and-shove mode to reroute; adjust board outline if space allows |
| KiCad version mismatch warning on open | File was saved with a newer KiCad version | Upgrade KiCad to match or newer; older versions may silently drop features |

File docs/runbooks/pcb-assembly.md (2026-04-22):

# Runbook: PCB Ordering and Assembly

## Prerequisites

- KiCad 9.0+ installed (to regenerate Gerbers if needed).
- Access to `PCB/DiceMaster_Router/gerbers/` — pre-exported Gerbers are committed, so re-export is only needed after schematic/layout changes.
- JLCPCB account (or PCBWay account as alternative).
- Component sourcing: DigiKey, LCSC, or JLCPCB parts catalog for SMD components; DigiKey or Adafruit for through-hole connectors.
- Fine-tip soldering iron and hot-air station, or use JLCPCB's SMT assembly service for SMD parts.

## Steps

### 1. Export Gerbers from KiCad (if files have changed)

1. Open `PCB/DiceMaster_Router/DiceMaster_Router.kicad_pro` in KiCad.
2. Open **PCB Editor**.
3. Run **DRC** (Inspect → Design Rules Checker). Resolve all errors before exporting.
4. Go to **File → Fabrication Outputs → Gerbers**.
5. Select output directory: `PCB/DiceMaster_Router/gerbers/`.
6. Enable all copper layers (F.Cu, B.Cu), edge cuts, silkscreen (F.Silkscreen, B.Silkscreen), soldermask (F.Mask, B.Mask), and paste (F.Paste, B.Paste).
7. Click **Plot**.
8. Then generate drill files: **File → Fabrication Outputs → Drill Files**. Export both PTH and NPTH drill files to the same gerbers directory.
9. Zip the contents of `gerbers/` — a pre-zipped archive is at `gerbers/DiceMaster_Router_gerbers.zip`.

### 2. Upload to JLCPCB

1. Go to [jlcpcb.com](https://jlcpcb.com) and click **Order Now**.
2. Upload `DiceMaster_Router_gerbers.zip`.
3. Set PCB parameters:
   - **Layers**: 2
   - **Dimensions**: ≤ 60 × 60 mm (verify from KiCad board outline)
   - **PCB thickness**: 1.6 mm
   - **Stackup**: FR4
   - **Copper weight**: 1 oz
   - **Surface finish**: HASL or LeadFree HASL (ENIG if budget allows — better for fine-pitch SOT-23 pads)
4. For **SMT Assembly (PCBA)**: toggle "PCB Assembly" on. Upload the BOM CSV (`gerbers/BOM_JLCPCB.csv`) and CPL CSV (`gerbers/DiceMaster_Router-CPL.csv`). Review component matches in the JLCPCB parts selector.

### 3. Component Sourcing

SMD components are sourced via JLCPCB's parts catalog (LCSC part numbers in the BOM) or DigiKey for alternatives. Key items to verify before ordering:

| Part | Critical Spec | Reference |
|---|---|---|
| TPS565201DDCR | SOT-23-6 buck converter | IC1 |
| L1 (3.3 µH inductor) | ≥ 3 A saturation current, NR-50xx 5 × 5 mm footprint (e.g., Sunlord SWPA5040S3R3NT) | L1 |
| C1, C3, C_OUT1–3 (22 µF, 0805) | **≥ 10 V voltage rating** — 6.3 V-rated parts derate severely at 5 V | capacitors |
| R_BOT1 (30.1 kΩ) | **1% tolerance** — sets 3.3 V output via feedback divider | R_BOT1 |
| Q_FAN1 (2N7002) | SOT-23, 115 mA continuous — only suitable for the WINSINN 30 mm 0.09 A fan; upgrade MOSFET for any larger fan | Q_FAN1 |
| D_FAN1 (1N5819) | SOD-323 Schottky (equivalent: 1N5819HW or B5819W) | D_FAN1 |

See `PCB/DiceMaster_Router/BOM_ordering_notes.md` for the full BOM with ordering notes.

### 4. Hand-Soldered Connectors

The following connectors are not included in JLCPCB PCBA — solder by hand after the board arrives:

| Ref | Part |
|-----|---|
| J1 | 2×20 pin socket header, 2.54 mm pitch (Raspberry Pi 40-pin female header) |
| J_A1–J_F1 | JST GH 6-pin SMD horizontal (SM06B-GHS-TB) |
| J_BTN1 | JST GH 5-pin SMD horizontal (SM05B-GHS-TB) |
| J_SWITCH1 | JST GH 3-pin SMD horizontal (SM03B-GHS-TB) |
| J_FAN1 | JST GH 2-pin SMD horizontal (SM02B-GHS-TB) |
| PiSugarPowerConnector1 | JST GH 2-pin SMD horizontal (SM02B-GHS-TB) |

The GY-BMI160 breakout (U1) mounts via 2.54 mm pin headers into a 7+5 pin socket footprint (10.16 mm row spacing).

### 5. SMD Soldering (if not using PCBA service)

1. Apply solder paste to SMD pads using a stencil (order stencil from JLCPCB on the same order).
2. Place components with tweezers. The TPS565201 SOT-23-6 is the most challenging part — use flux and a fine iron tip or hot-air at ~300 °C.
3. Reflow on a hotplate or in a toaster-oven reflow setup.
4. Inspect under magnification; touch up any bridges with flux and solder wick.

## Verify

1. **Visual inspection**: check all SMD pads for solder bridges, especially under IC1 (TPS565201 SOT-23-6).
2. **Continuity test (before powering on)**:
   - Measure resistance between 3.3 V rail and GND with a multimeter (should be several kΩ, not a short).
   - Probe each JST GH connector pin against the schematic nets.
3. **Power-on test**:
   - Apply 5 V to the PiSugar power connector.
   - Measure 3.3 V on the 3.3 V rail output (within ±2% = 3.234–3.366 V).
4. **Functional test**:
   - Seat the Raspberry Pi on J1.
   - Connect one face module via J_A1.
   - Boot the Pi and verify SPI communication with the ESP32-S3 on that face.

## Troubleshooting

| Symptom | Likely Cause | Fix |
|---|---|-----|
| No 3.3 V output | TPS565201 not soldering properly, or L1 saturation current exceeded | Reflow IC1; verify L1 is ≥3 A rating |
| 3.3 V output too high or too low | R_BOT1 wrong value or wrong tolerance | Verify R_BOT1 is 30.1 kΩ ±1% |
| Fan does not spin | Q_FAN1 gate not driven, or MOSFET damaged | Check PWM signal on gate; verify D_FAN1 is not shorted |
| Intermittent SPI errors | Bad JST cable crimp or wrong pin mapping | Re-seat JST connectors; verify cable wiring against schematic |
| Pi does not boot | 3.3 V rail sagging under load | Check all C_OUT capacitors are ≥10 V rated; check L1 saturation rating |

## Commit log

2026-04-05 rough schematic added
    [DiceMaster_Router.kicad_pcb, DiceMaster_Router.kicad_sch]
2026-04-05 Finished PCB v1
    [DiceMaster_Router.kicad_pcb, DiceMaster_Router.kicad_sch]
2026-04-05 finalized pcb v1 for prod
    [DiceMaster_Router-B_Cu.gbr, DiceMaster_Router-B_Mask.gbr, DiceMaster_Router-B_Paste.gbr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]
2026-04-22 Add project documentation framework (ADRs, architecture, runbooks)
    Adds decisions/, architecture/, and runbooks/ under docs/.
    Covers hardware architecture (Router PCB, SPI pinouts, power rail),
    KiCad tooling rationale, custom PCB vs dev board decision, PCB assembly
    guide, and KiCad setup runbook.
2026-04-22 Ignore KiCad Plugins directory, remove freerouting zip from history
    The freerouting plugin zip (58 MB) was never used and exceeded GitHub's
    recommended file size limit. Stripped from history with git-filter-repo
    and added PCB/*/Plugins/ to .gitignore.
2026-07-09 Feat/daniel handoff (#1)
    * docs: note PCB v1 known issues (JST ports, 5V→3.3V converter) in README
    Record two unverified issues on the v1 boards (finalized 2026-04-05, received
    ~mid-April 2026):
    - Some JST GH connectors could not be soldered during manufacturing
    - The TPS565201 5V→3.3V buck converter (IC1) never produced a working 3.3V
    rail; unknown whether design or soldering issue — to be handled later
    * chore: ignore AI agent files; untrack committed PCB/.DS_Store
2026-09-15 addev v2 shell 3D designs (#2)
    [Base Frame.f3d, Base Frame.stl, Button Plate.f3d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]
